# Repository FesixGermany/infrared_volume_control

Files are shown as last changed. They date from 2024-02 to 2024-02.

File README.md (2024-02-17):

# Infrared volume control
 Digital audio volume controller for use with IR remote  

 ## Origin of project
 My friend pandora has a Philips TV with okay sound but not great. Would be nice to have some additional speakers.  
 Speakers can be connected to a headphone jack but volume can not be easily changed without entering two submenus of the TV.  
 The solution: Our own PCB with an IR receiver and an Arduino who decodes the commands "volume up" and "volume down" from the IR remote sent as RC6 protocol. These commands then are used to change the value of two digital potentiometers, one for each audio channel after the loudspeakers of the TV are diabled in the settings.

 ## Circuit
 TSOP34836 for demodulating the 36kHz IR signal, can be changed for other carrier frequencies.  
 Arduino nano clone with USB-C for all things digital.  
 MCP4151 digital potentiometer for attenuating audio level.  
 Inductors for filtering some noise on the power rails, especially when SPI is active.  
Resistors and capacitors for creating a virtual ground.  

## Housing
Simple 3D printed case, nothing fancy.  
  
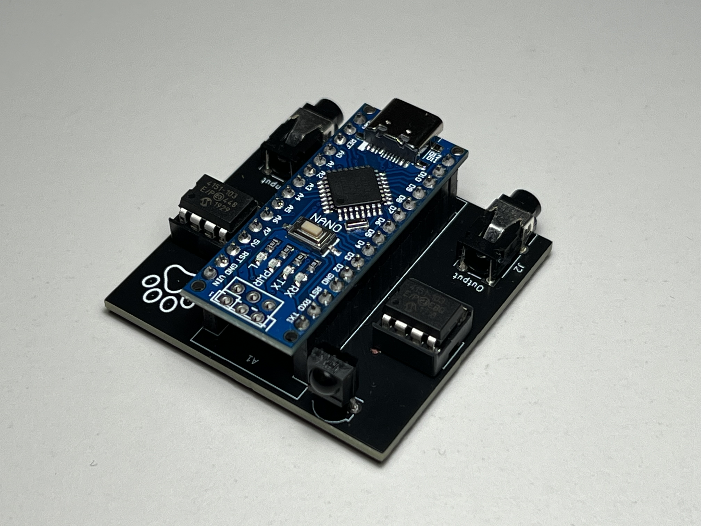
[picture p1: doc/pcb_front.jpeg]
Front of PCB
  
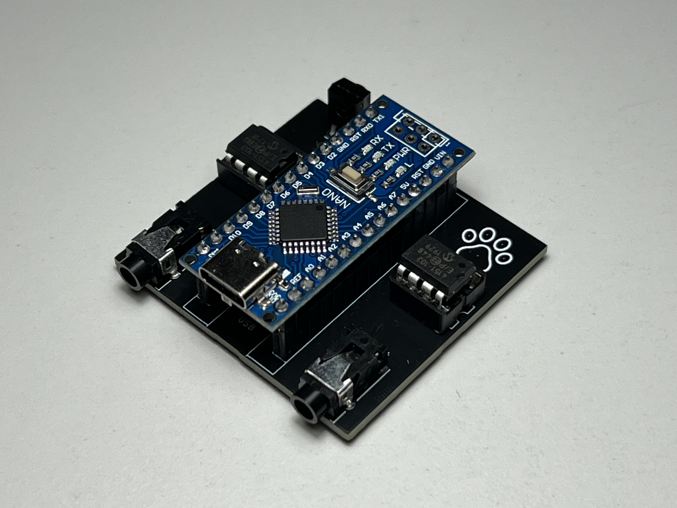
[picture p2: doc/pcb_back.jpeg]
Back of PCB
  
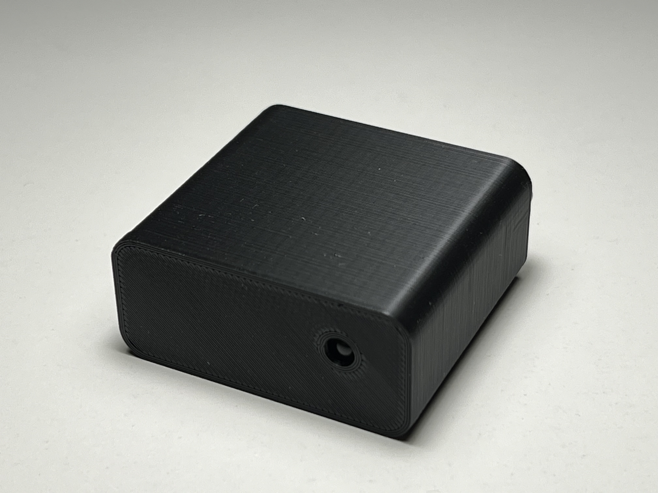
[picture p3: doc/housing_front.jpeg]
Front of housing
  
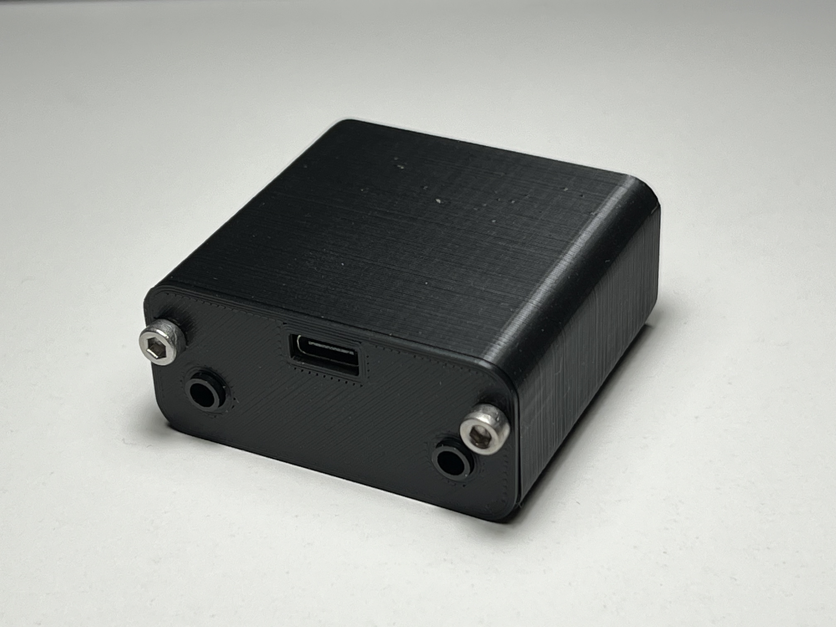
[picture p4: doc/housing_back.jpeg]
Back of housing


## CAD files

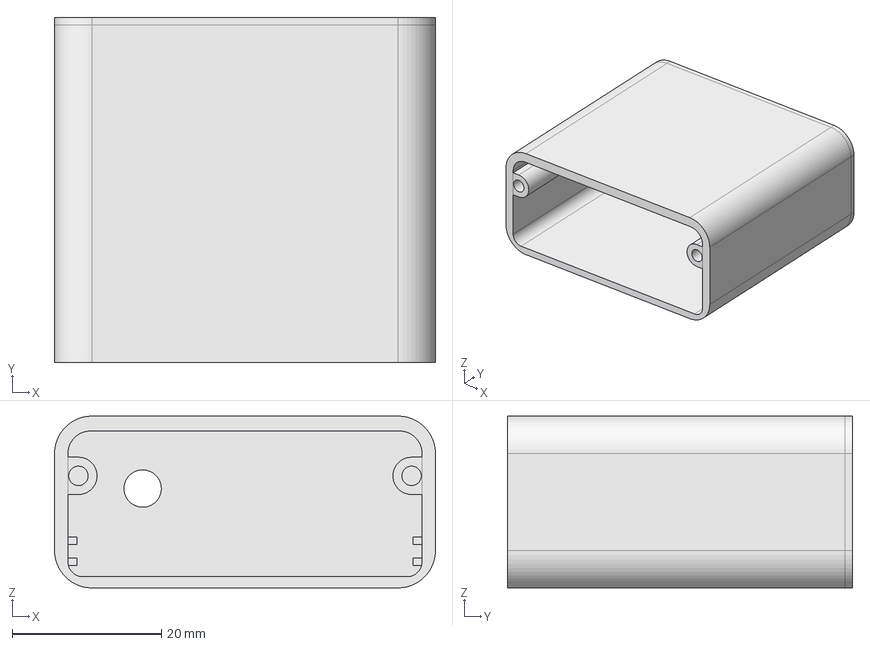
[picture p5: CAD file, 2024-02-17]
housing/housing-main_housing.step
51.0 x 46.2 x 23.0 mm

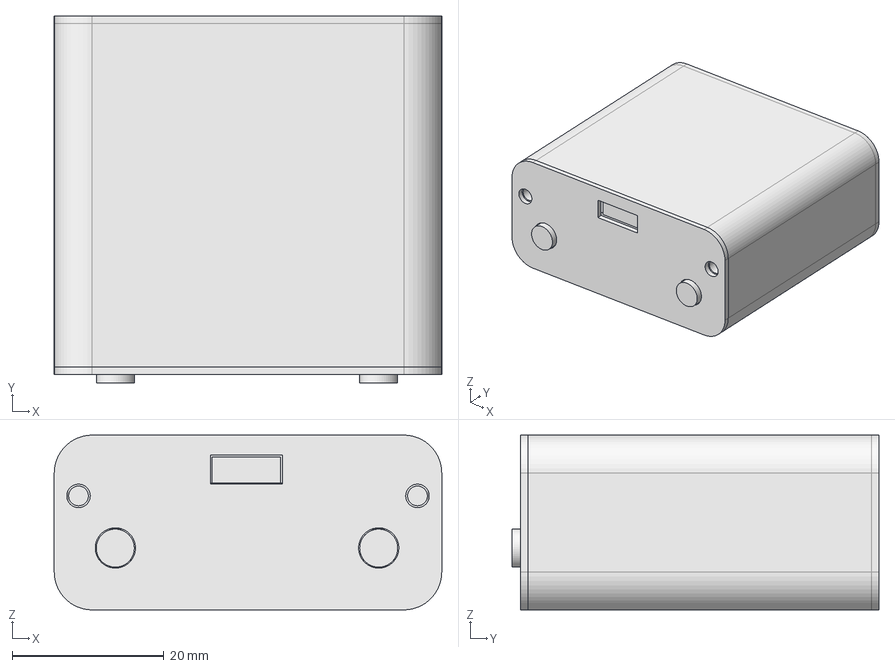
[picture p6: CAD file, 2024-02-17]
housing/housing.FCStd
51.0 x 48.3 x 23.0 mm
ir_remote_control PCB
main housing
back cover

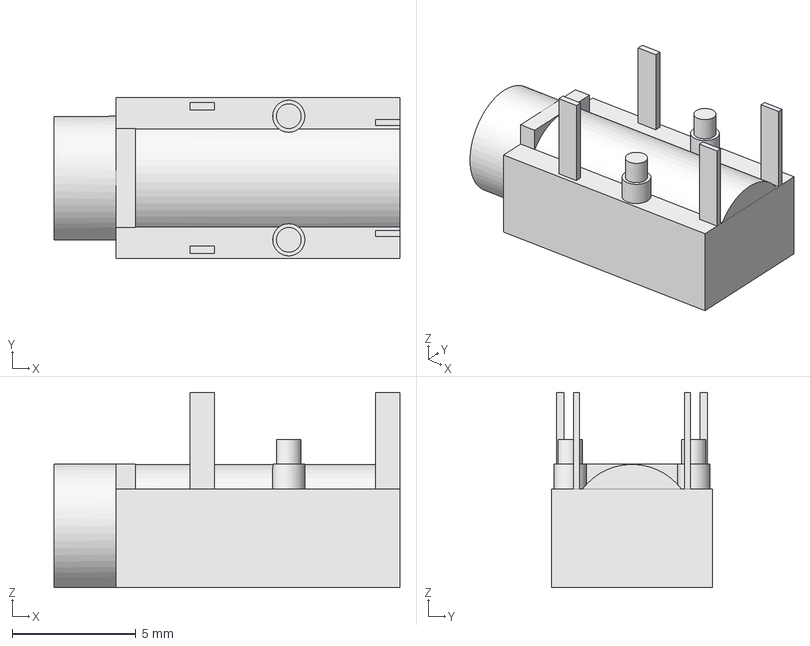
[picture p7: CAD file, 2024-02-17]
pcb/3D/ST-005-G-Body.step
14.0 x 6.50 x 7.90 mm

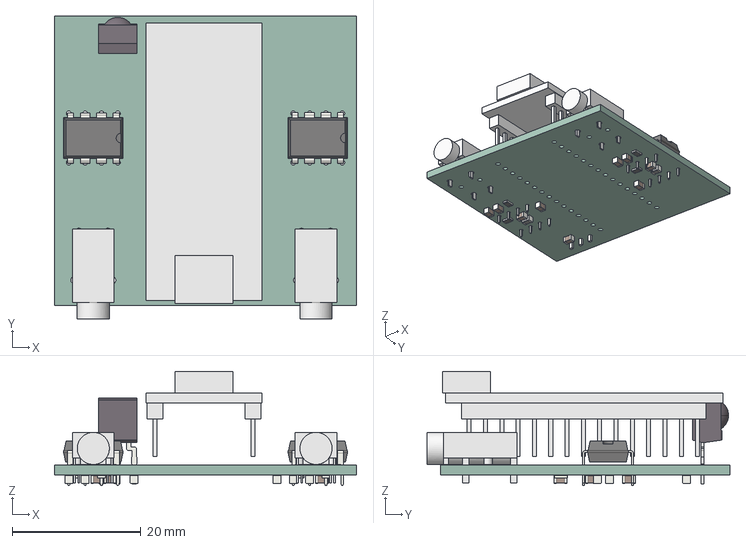
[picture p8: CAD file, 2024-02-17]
pcb/pcb.step
47.0 x 47.1 x 17.8 mm
ir_remote_control PCB

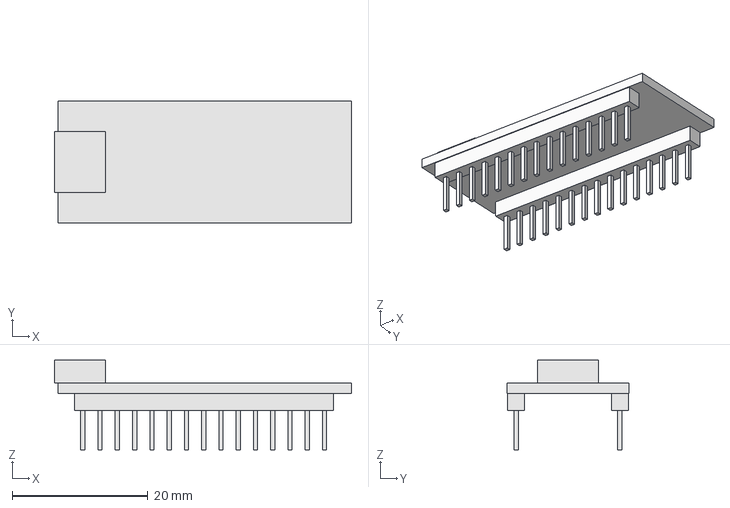
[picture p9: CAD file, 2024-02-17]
pcb/3D/Arduino_nano_clone_usbc-Body.step
43.7 x 18.0 x 13.2 mm

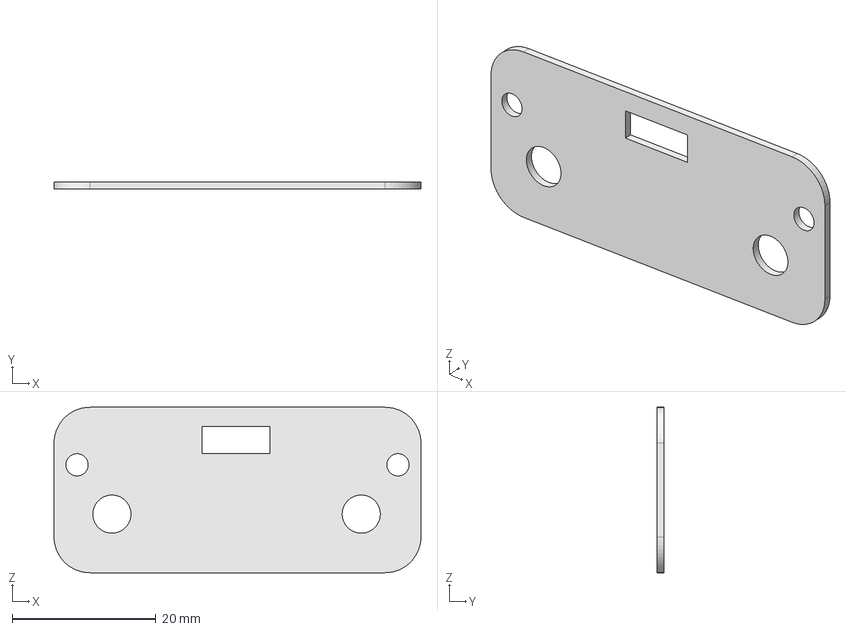
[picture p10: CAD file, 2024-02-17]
housing/housing-back_cover.step
51.0 x 1.00 x 23.0 mm

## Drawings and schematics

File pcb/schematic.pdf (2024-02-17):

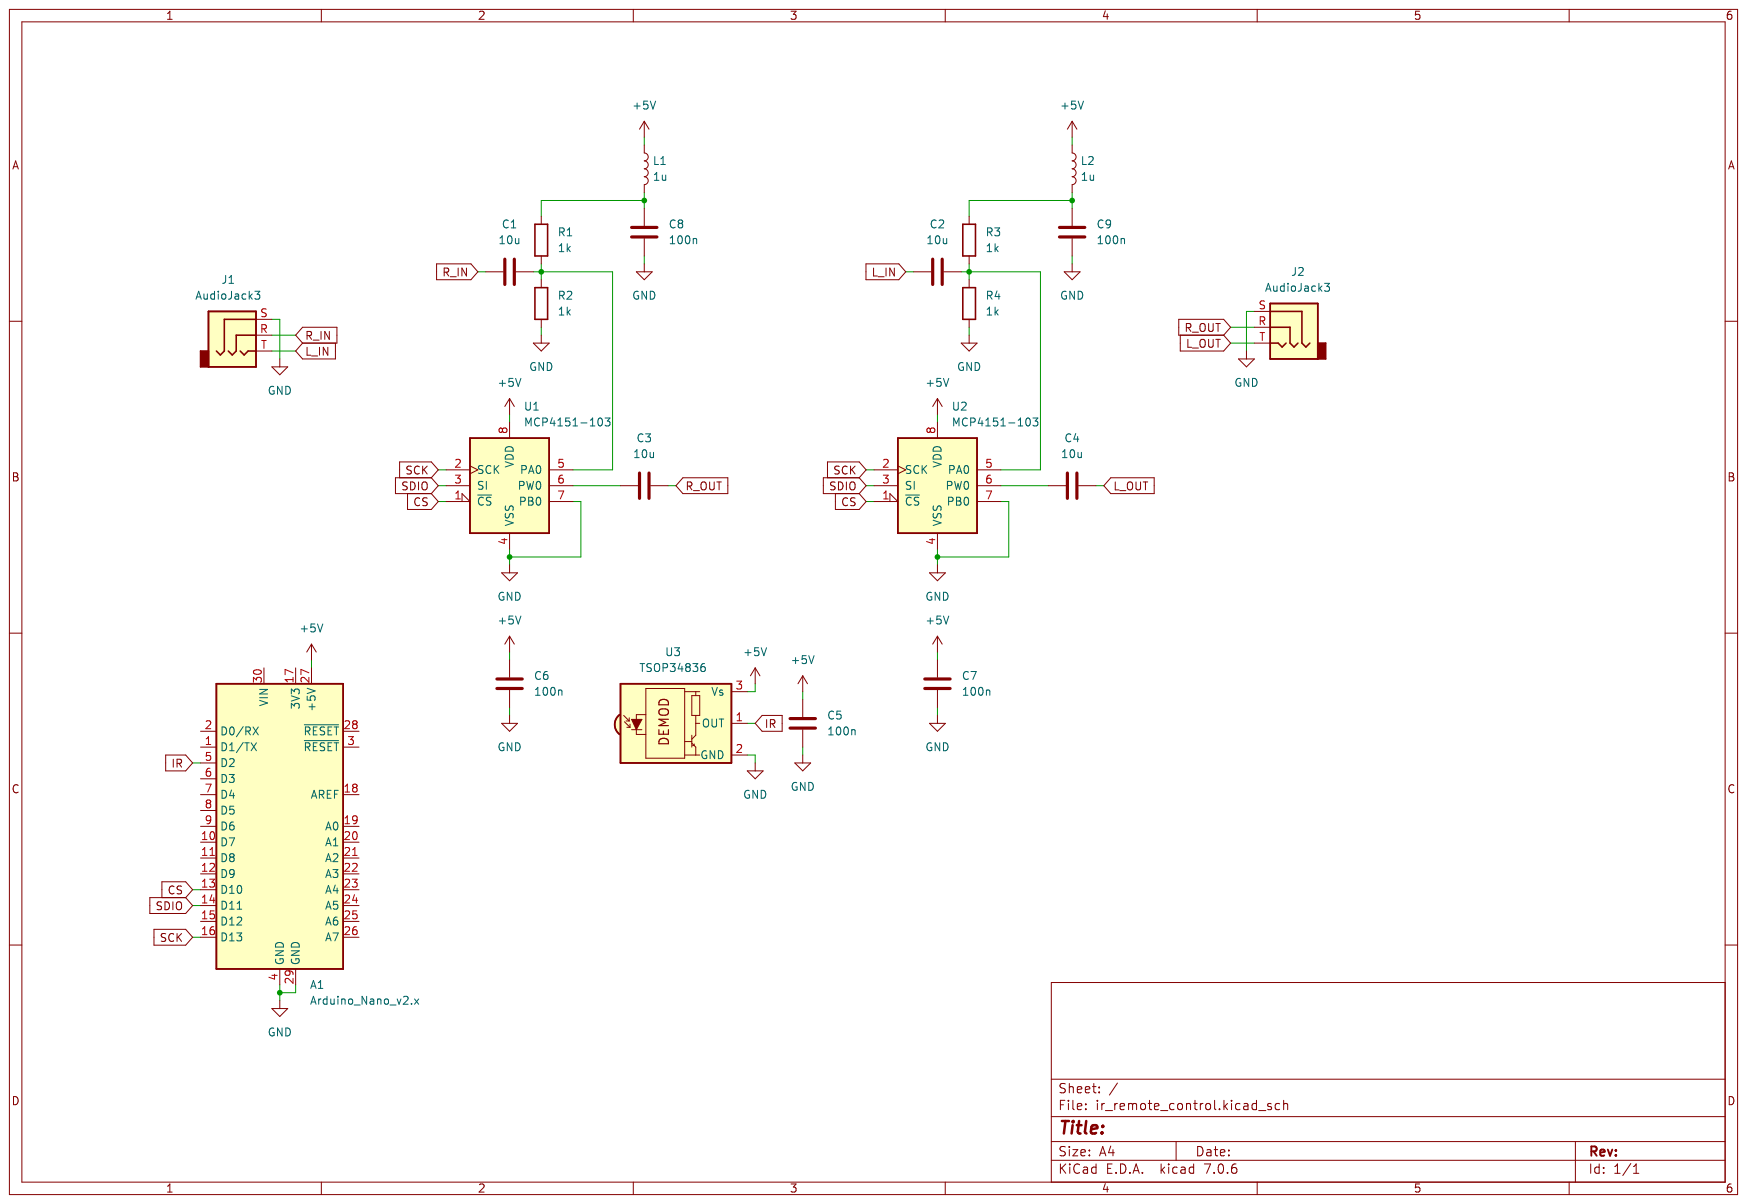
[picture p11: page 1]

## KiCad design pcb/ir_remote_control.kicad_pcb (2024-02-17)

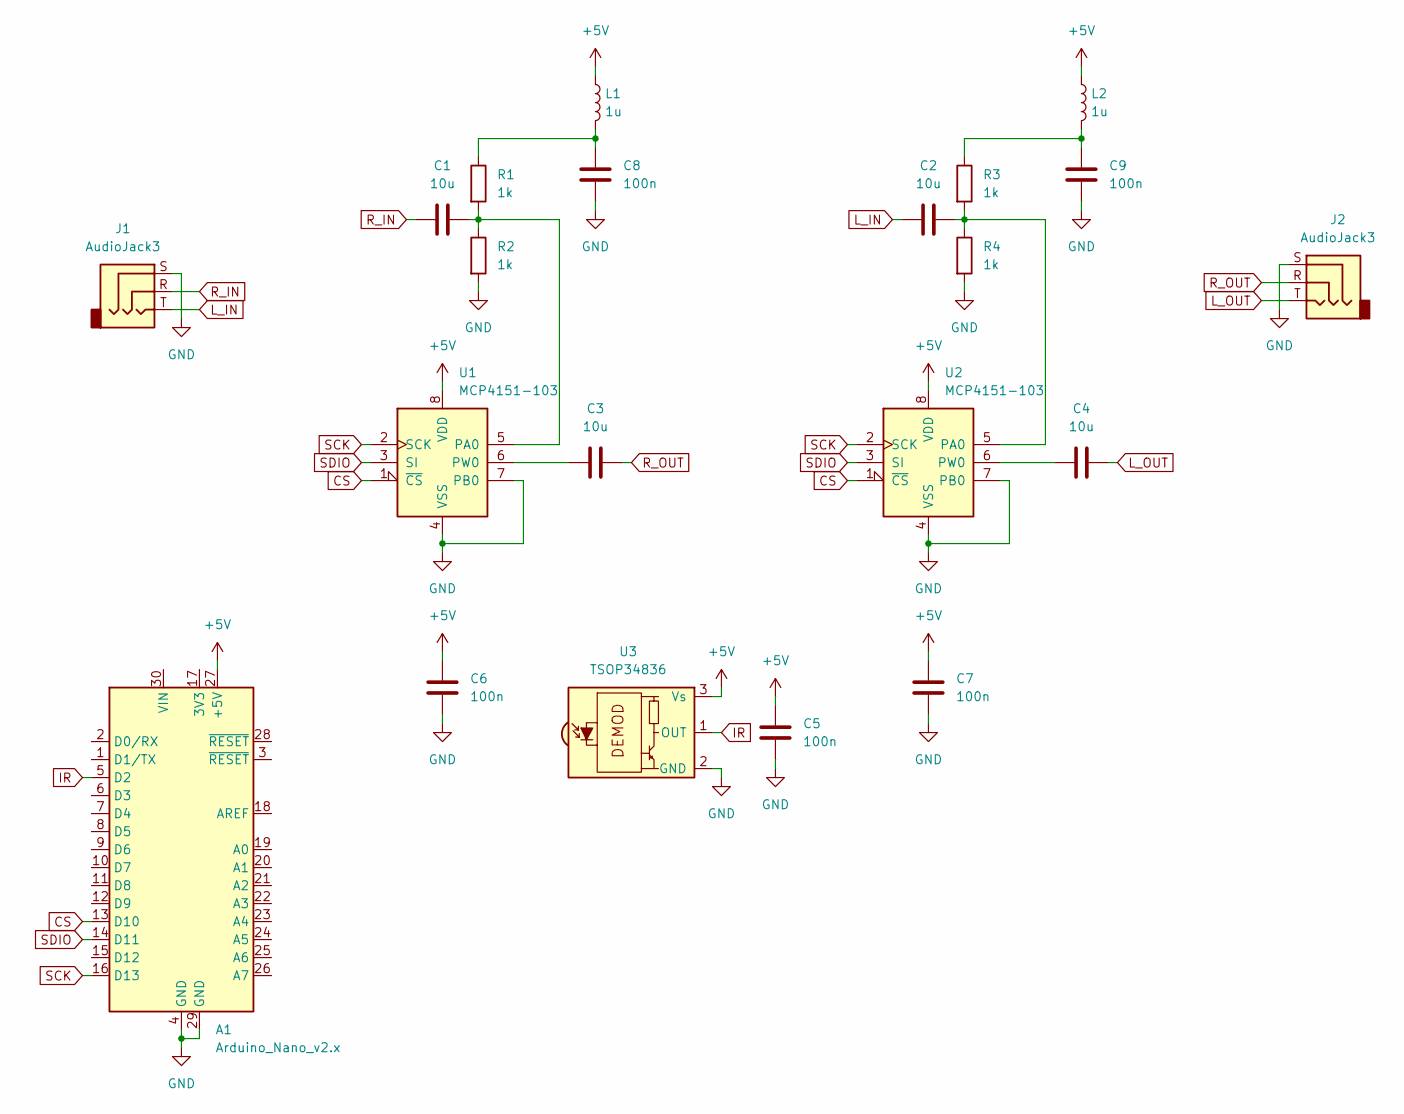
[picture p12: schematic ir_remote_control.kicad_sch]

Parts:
A1: Arduino_Nano_v2.x; Arduino_Nano
C1, C2, C3, C4: 10u; C_0805_2012Metric_Pad1.18x1.45mm_HandSolder
C5, C6, C7, C8, C9: 100n; C_0805_2012Metric_Pad1.18x1.45mm_HandSolder
J1, J2: AudioJack3; Jack_3.5mm_Switronic_ST-005-G_horizontal
L1, L2: 1u; L_0805_2012Metric_Pad1.15x1.40mm_HandSolder
R1, R2, R3, R4: 1k; R_0805_2012Metric_Pad1.20x1.40mm_HandSolder
U1, U2: MCP4151-103; DIP-8_W7.62mm
U3: TSOP34836; Vishay_MOLD-3Pin

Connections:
+5V: A1.27 (+5V), C5.1, C6.1, C7.1, L1.1, L2.1, U1.8 (VDD), U2.8 (VDD), U3.3 (Vs)
CS: A1.13 (D10), U1.1 (~CS), U2.1 (~CS)
GND: A1.4 (GND), A1.29 (GND), C5.2, C6.2, C7.2, C8.2, C9.2, J1.S, J2.S, R2.2, R4.2, U1.4 (VSS), U1.7 (PB0), U2.4 (VSS), U2.7 (PB0), U3.2 (GND)
IR: A1.5 (D2), U3.1 (OUT)
L_IN: C2.1, J1.T
L_OUT: C4.2, J2.T
unnamed: C8.1, L1.2, R1.1
unnamed: C9.1, L2.2, R3.1
unnamed: C1.2, R1.2, R2.1, U1.5 (PA0)
unnamed: C3.1, U1.6 (PW0)
unnamed: C2.2, R3.2, R4.1, U2.5 (PA0)
unnamed: C4.1, U2.6 (PW0)
R_IN: C1.1, J1.R
R_OUT: C3.2, J2.R
SCK: A1.16 (D13), U1.2 (SCK), U2.2 (SCK)
SDIO: A1.14 (D11), U1.3 (SI), U2.3 (SI)

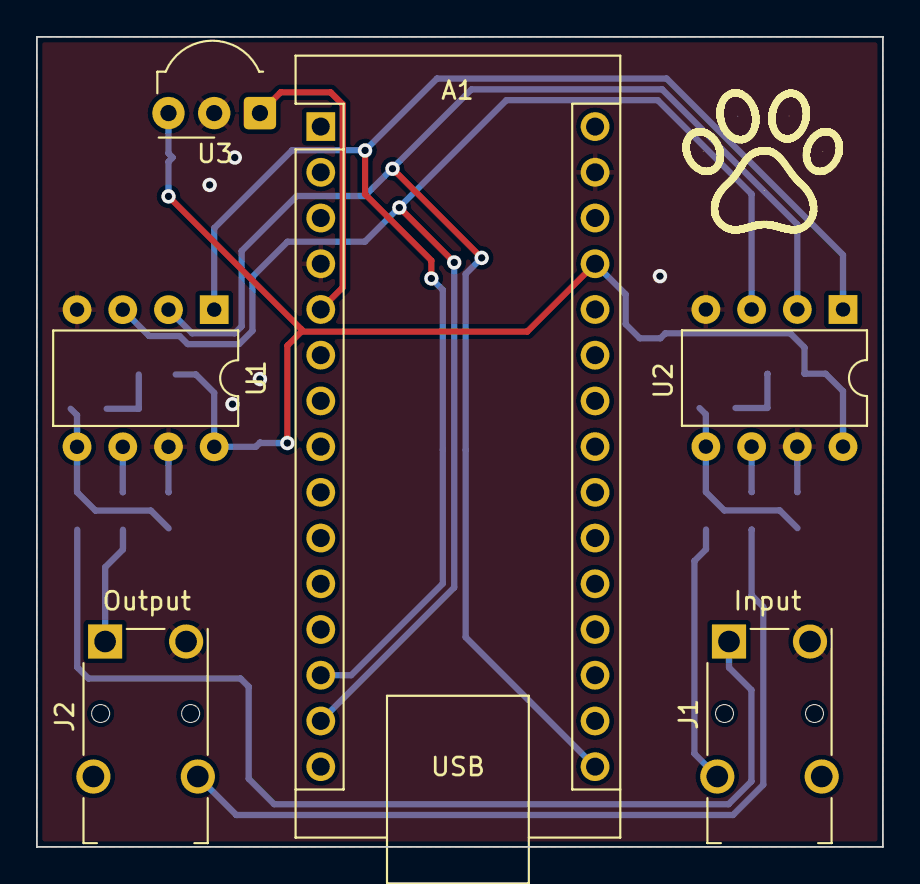
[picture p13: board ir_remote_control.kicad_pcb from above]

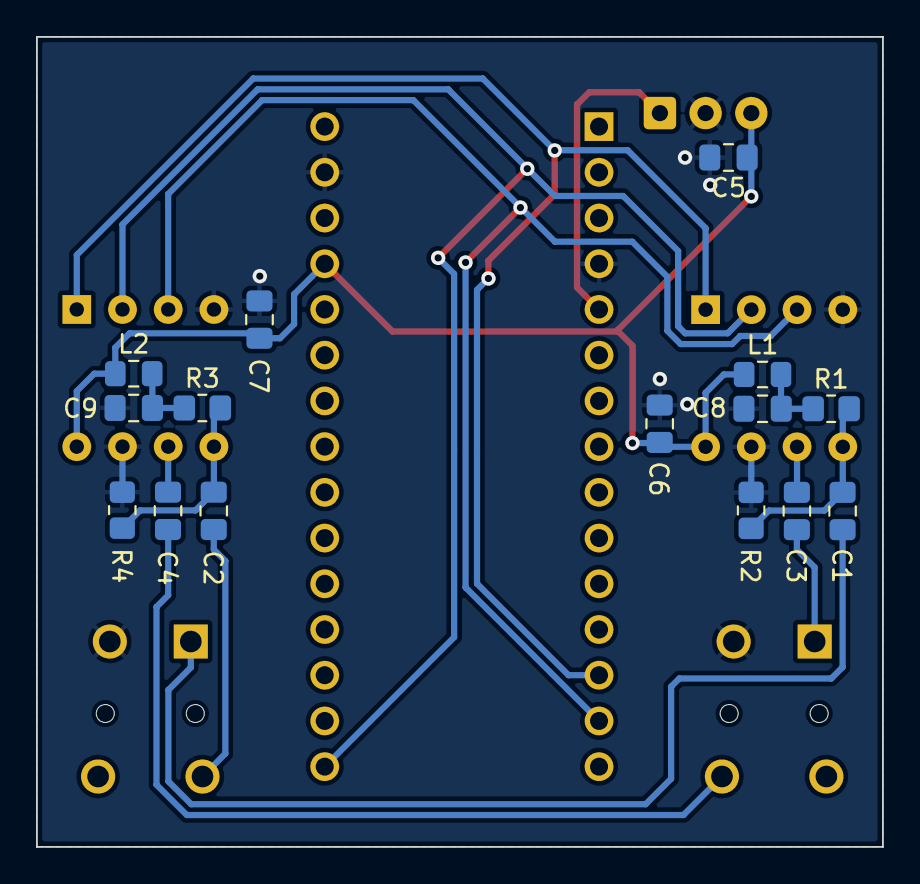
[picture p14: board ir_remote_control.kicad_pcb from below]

Board: 2 copper layers, 47.0 x 45.0 mm, 21 parts (15 on the bottom side), 16 nets.

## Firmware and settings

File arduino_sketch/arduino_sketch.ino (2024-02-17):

/*
*
* Program for Arduino nano to receive volume up and volume down command from Philips IR TV remote (RC6 protocol).
* Command is used to set a digital MCP4151 potentiometer for external volume control.
* Additional serial output for debugging.
* Code by pandora
*
*/

#include <IRremote.h>
#include <MCP4151.h>

#define CS     10
#define MOSI   11
#define MISO   12
#define SCK    13

MCP4151 pot(CS, MOSI, MISO, SCK);

// Pin where the IR receiver is connected to
const int irReceivePin = 2;

IRrecv irrecv(irReceivePin);
decode_results results;

// Initial pot value after restart
int value = 128;

void setup()
{
  pot.writeValue(value);
  Serial.begin(9600);
  irrecv.enableIRIn();
}


void loop() {
  Serial.println(value, DEC);
  if (irrecv.decode(&results)){
      if (results.decode_type == RC6) {
        Serial.print("-decoded RC6: ");
        Serial.print("Value = ");
        Serial.println(results.value, DEC);

        // Lower pot value if volume up
        if (results.value == 17 || results.value == 65553){
            Serial.println("lauter");
            value -= 5;
            if (value < 0)
              value = 0;
            pot.writeValue(value);
            }
        // Higher pot value if volume down
        else if (results.value == 16 || results.value == 65552){
          Serial.println("leiser");
            value += 5;
            if (value > 254)
              value = 254;
          pot.writeValue(value);
          }
      }

    
      // showReceivedData();
      irrecv.resume();
  }
 
  delay(200);
}

// Serial output for debugging
void showReceivedData()
{
  if (results.decode_type == UNKNOWN){
    Serial.println("-Could not decode message");
    }
  else{
    if (results.decode_type == NEC) {
      Serial.print("- decoded NEC: ");
    }
  else if (results.decode_type == SONY) {
      Serial.print("- decoded SONY: ");
    }
  else if (results.decode_type == RC5) {
      Serial.print("-decoded RC5: ");
    }
  else if (results.decode_type == RC6) {
      Serial.print("-decoded RC6: ");
    }
  Serial.print("Value = ");
  Serial.println(results.value, HEX);
  }
}
